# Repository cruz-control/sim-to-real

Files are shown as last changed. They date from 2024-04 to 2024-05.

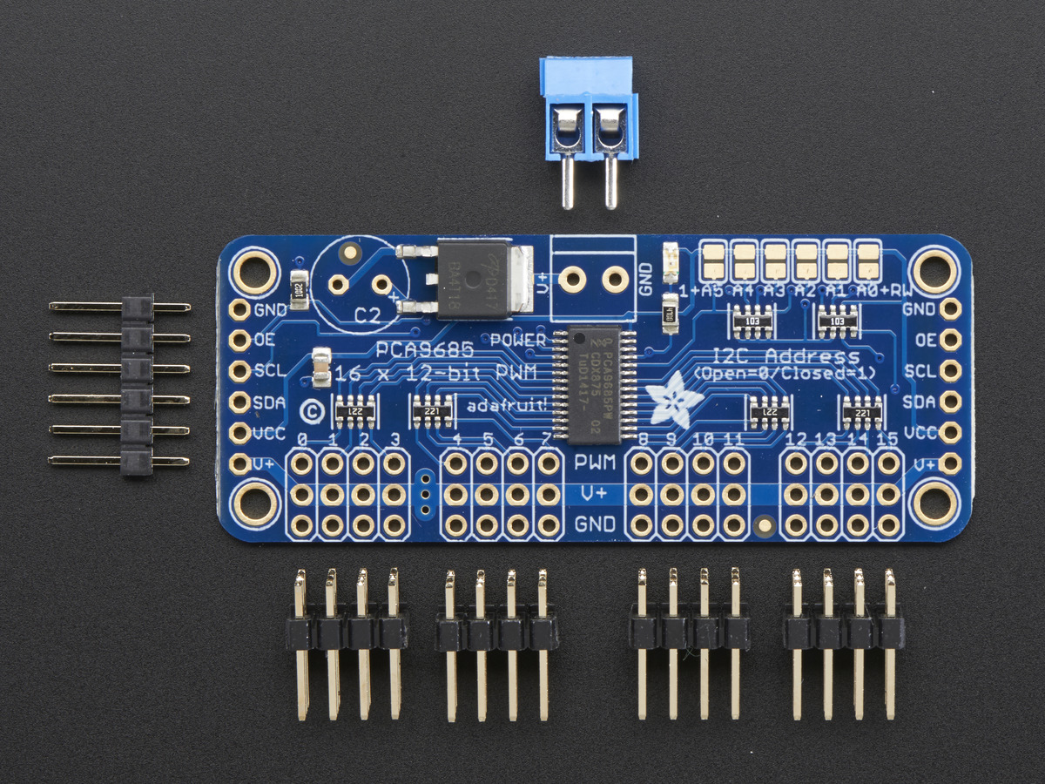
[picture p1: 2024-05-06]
PCB_v3/Adafruit-16-Channel-PWM-Servo-Driver-PCB-master/assets/image.jpg

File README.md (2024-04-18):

# Sim-to-real Team

Notes: (4/17/24) 

Solutions:
Got Jetson.GPIO to import by copying into the code directory
Got voltage out on controll pin (jetson servo PWM test)

Issues:
Get Jetson.GPIO to import from default download
Get the servo to run

Links:

Gave us test code
https://forums.developer.nvidia.com/t/strange-behaviour-with-jetson-nano-devkit-pwm-signal/113004/2

Gave us secondary test code
https://stackoverflow.com/questions/69114674/enabling-and-working-with-jetson-gpio-pins-with-python

Possible solution to Jetson.GPIO importing into python
https://forums.developer.nvidia.com/t/jetson-gpio-is-installed-but-cannot-be-imported/264719

Other possible help for identifying PWM and using PWM
https://kernel.org/doc/Documentation/pwm.txt

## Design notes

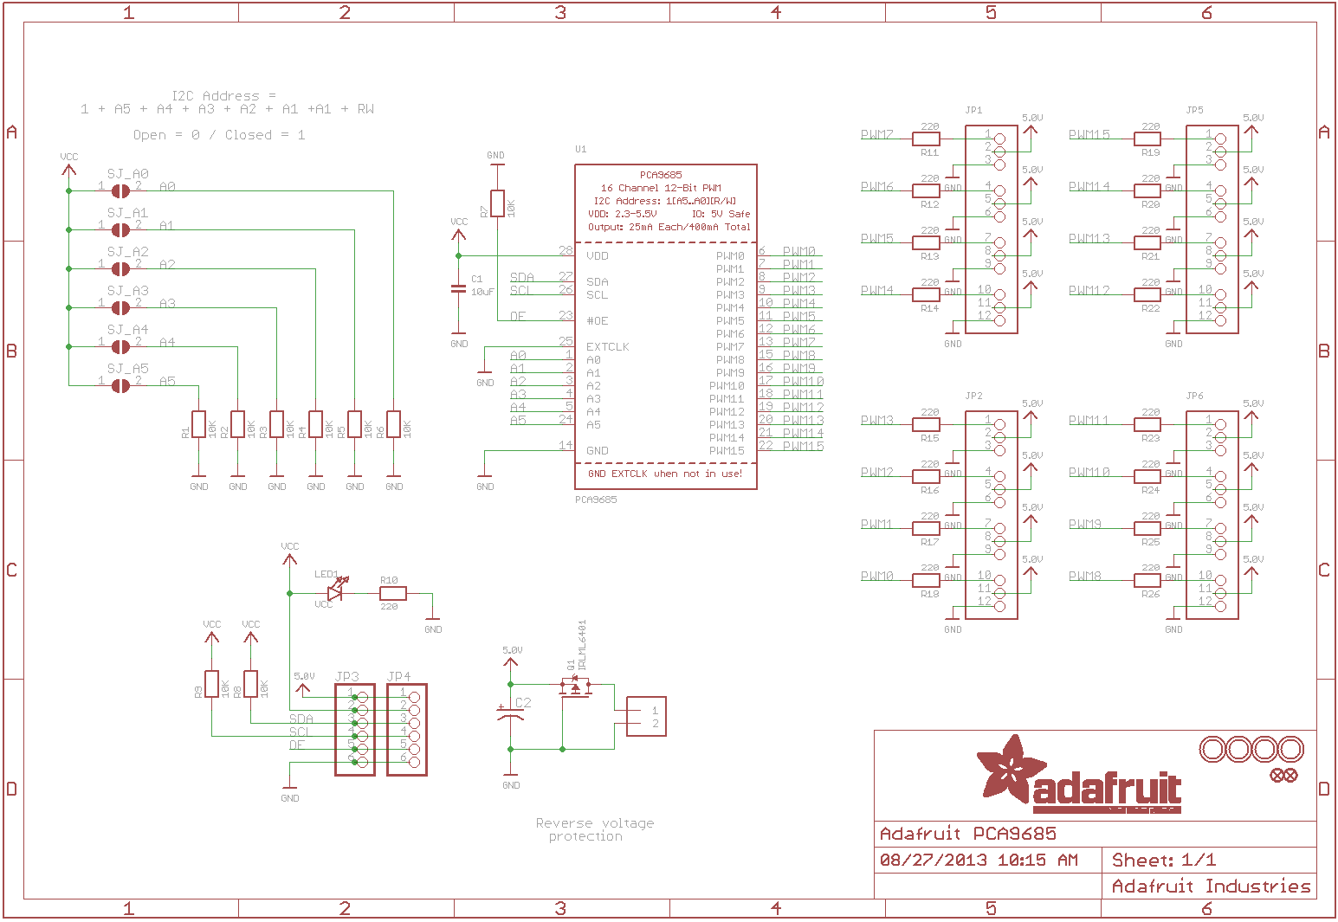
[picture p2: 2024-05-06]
PCB_v3/Adafruit-16-Channel-PWM-Servo-Driver-PCB-master/Adafruit PCA9685.png

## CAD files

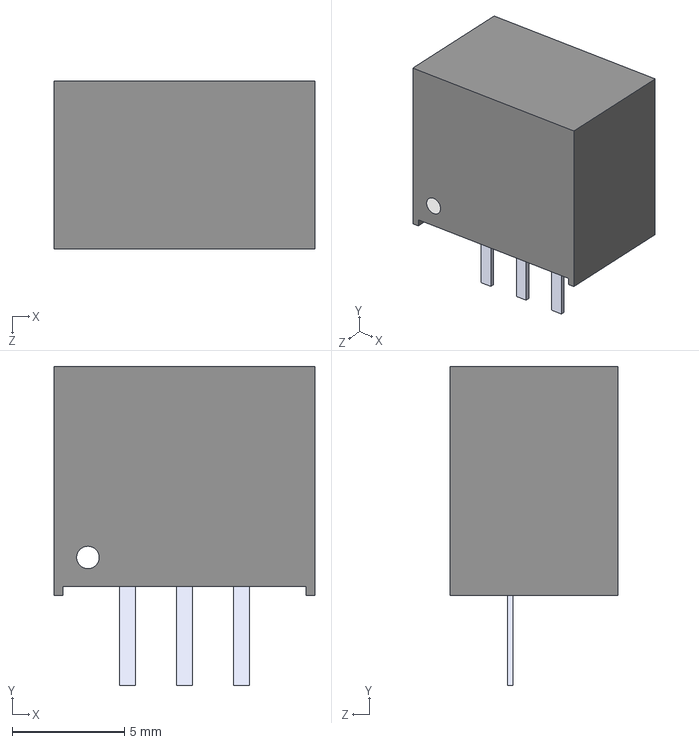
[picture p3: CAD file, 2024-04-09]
pcb-1/3d/LC78_05-3.0.STEP
11.6 x 14.2 x 7.50 mm

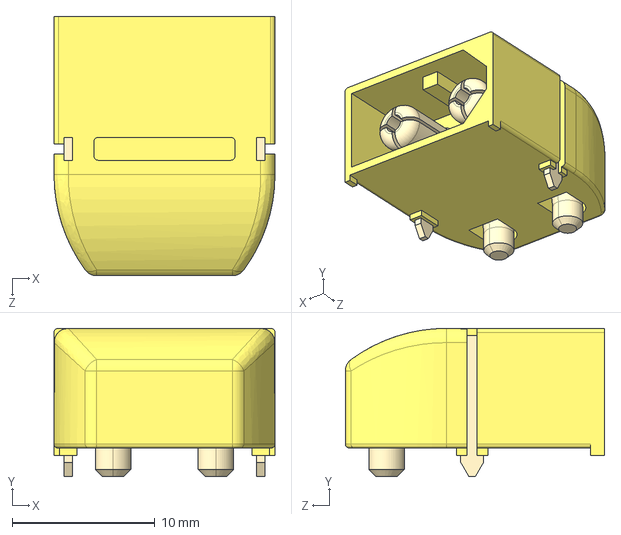
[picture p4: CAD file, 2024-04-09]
pcb-1/3d/XT60PW MALE.STEP
15.5 x 10.4 x 18.2 mm

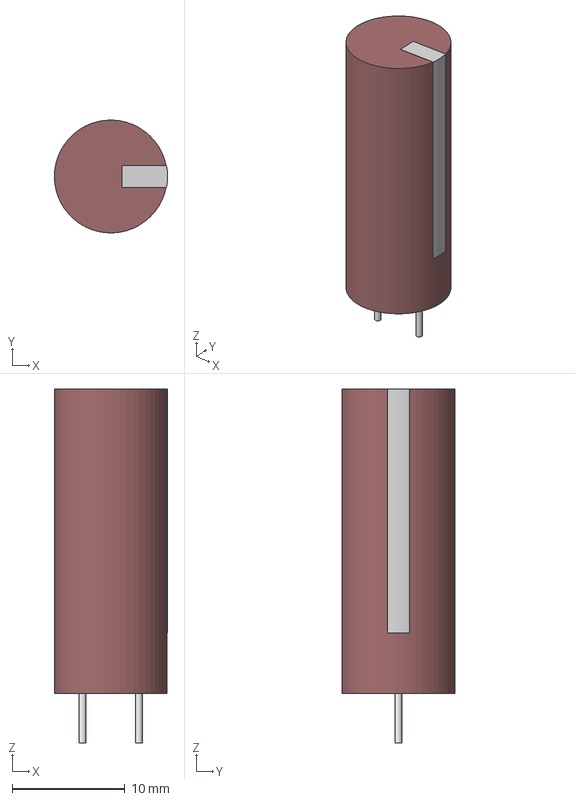
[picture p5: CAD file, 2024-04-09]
pcb-1/3d/CAP_UAQ_10X25_NCH.step
10.0 x 10.0 x 31.4 mm

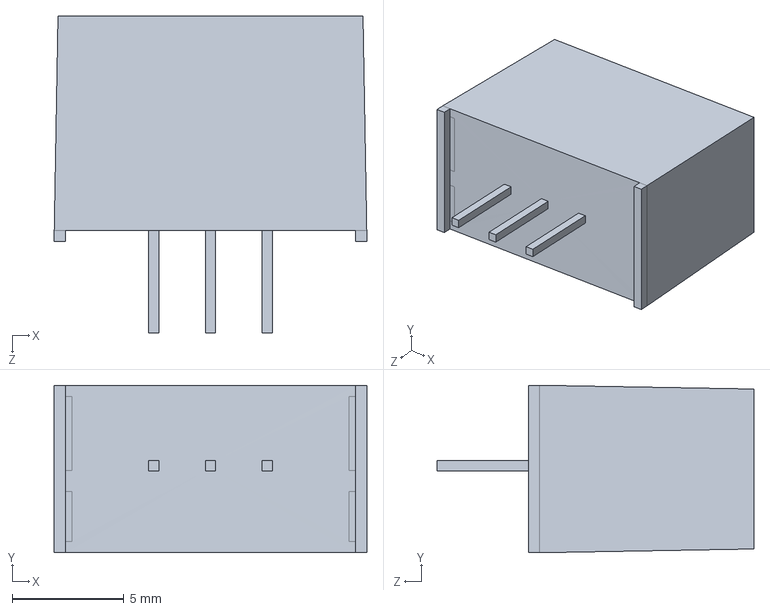
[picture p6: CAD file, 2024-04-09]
pcb-1/3d/tsr2_3d_drawing.stp
14.0 x 7.50 x 14.2 mm

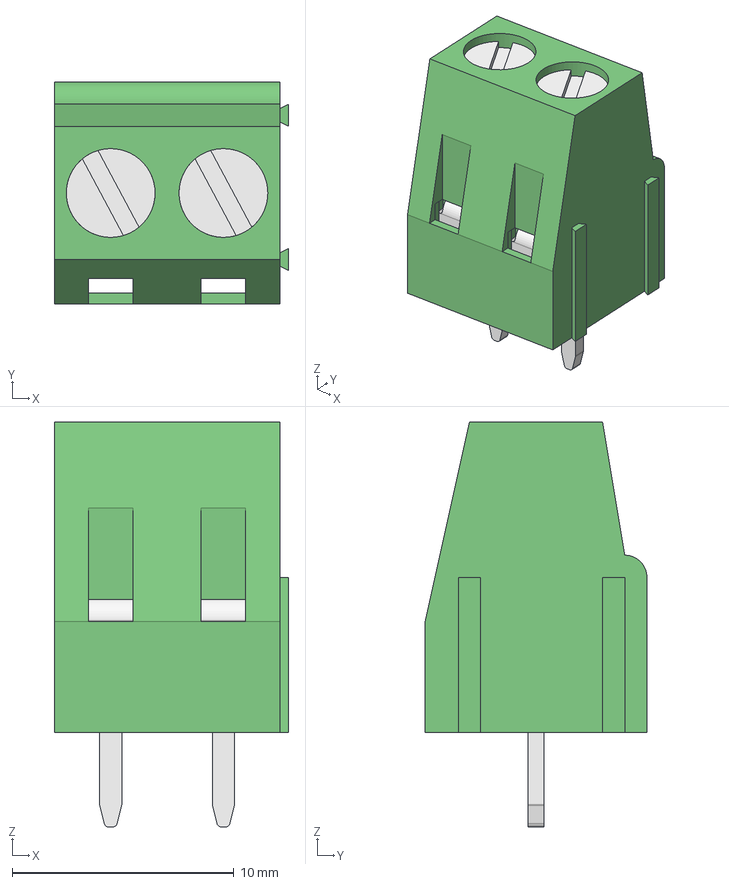
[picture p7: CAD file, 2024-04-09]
pcb-1/3d/Terminal Block 2P.step
10.6 x 10.0 x 18.2 mm
Pin (1) (19)
Tornillo (1) (19)
Cubo interno (1) (19)
Pin (1) (1) (18)
Tornillo (1) (1) (18)
Cubo interno (1) (1) (18)
Pin (1) (11)
Tornillo (1) (11)
Cubo interno (1) (11)
Pin (1) (1) (10)
Tornillo (1) (1) (10)
Cubo interno (1) (1) (10)

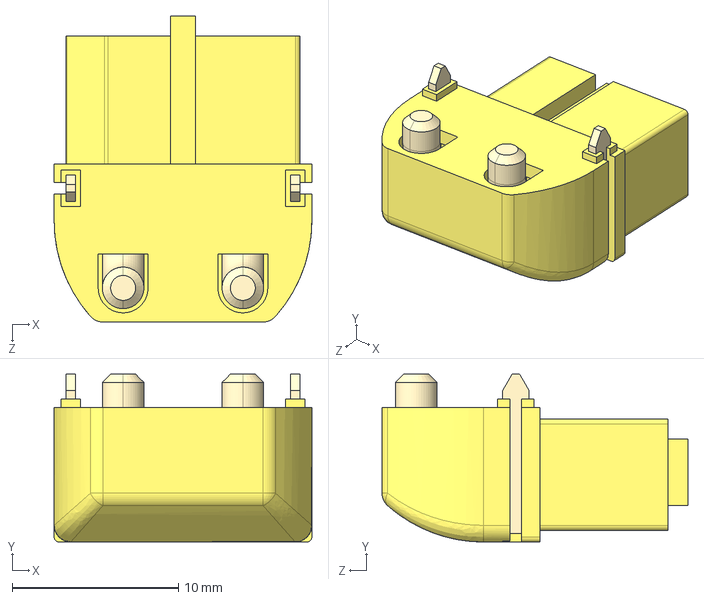
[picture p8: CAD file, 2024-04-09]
pcb-1/3d/XT60PW FEMALE.STEP
15.5 x 10.1 x 18.4 mm

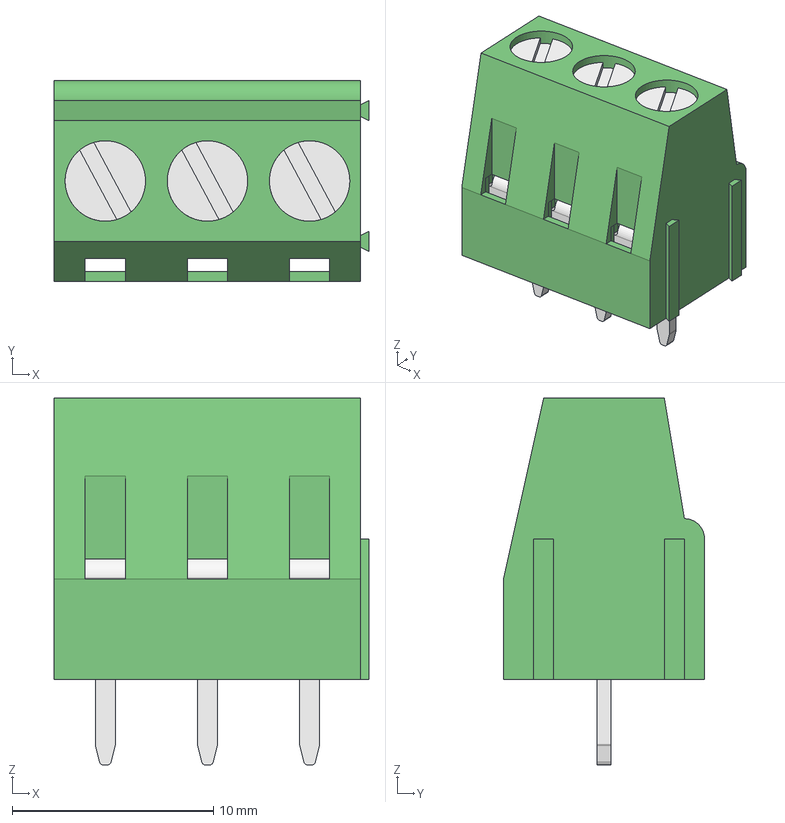
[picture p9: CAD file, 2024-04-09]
pcb-1/3d/Terminal Block 3P.step
15.6 x 10.0 x 18.2 mm
Pin (1) (19) (1)
Tornillo (1) (19) (1)
Cubo interno (1) (19) (1)
Pin (1) (1) (18) (1)
Tornillo (1) (1) (18) (1)
Cubo interno (1) (1) (18) (1)
Pin (1) (11) (1)
Tornillo (1) (11) (1)
Cubo interno (1) (11) (1)
Pin (1) (1) (10) (1)
Tornillo (1) (1) (10) (1)
Cubo interno (1) (1) (10) (1)
Pin (1) (17)
Tornillo (1) (17)
Cubo interno (1) (17)
Pin (1) (1) (16)
Tornillo (1) (1) (16)
Cubo interno (1) (1) (16)

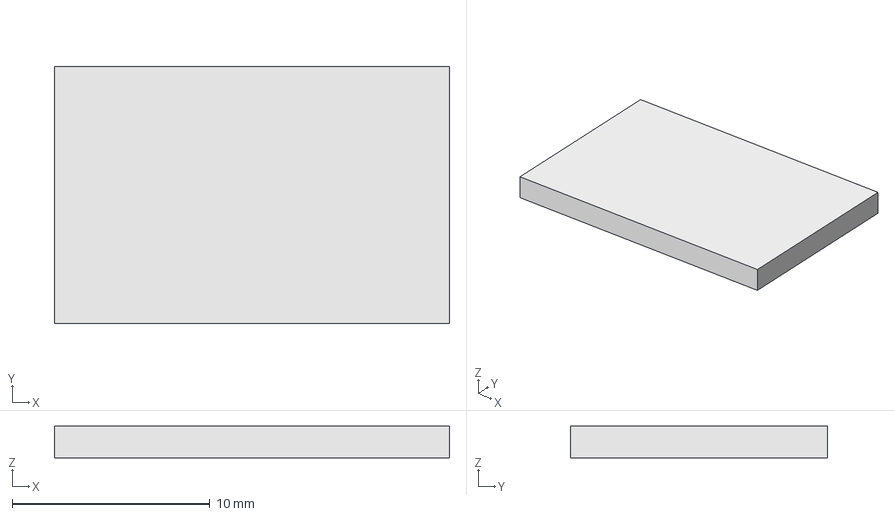
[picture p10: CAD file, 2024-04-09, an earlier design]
pcb-v2/3d/Unnamed2-Cube.step
20.0 x 13.0 x 1.60 mm

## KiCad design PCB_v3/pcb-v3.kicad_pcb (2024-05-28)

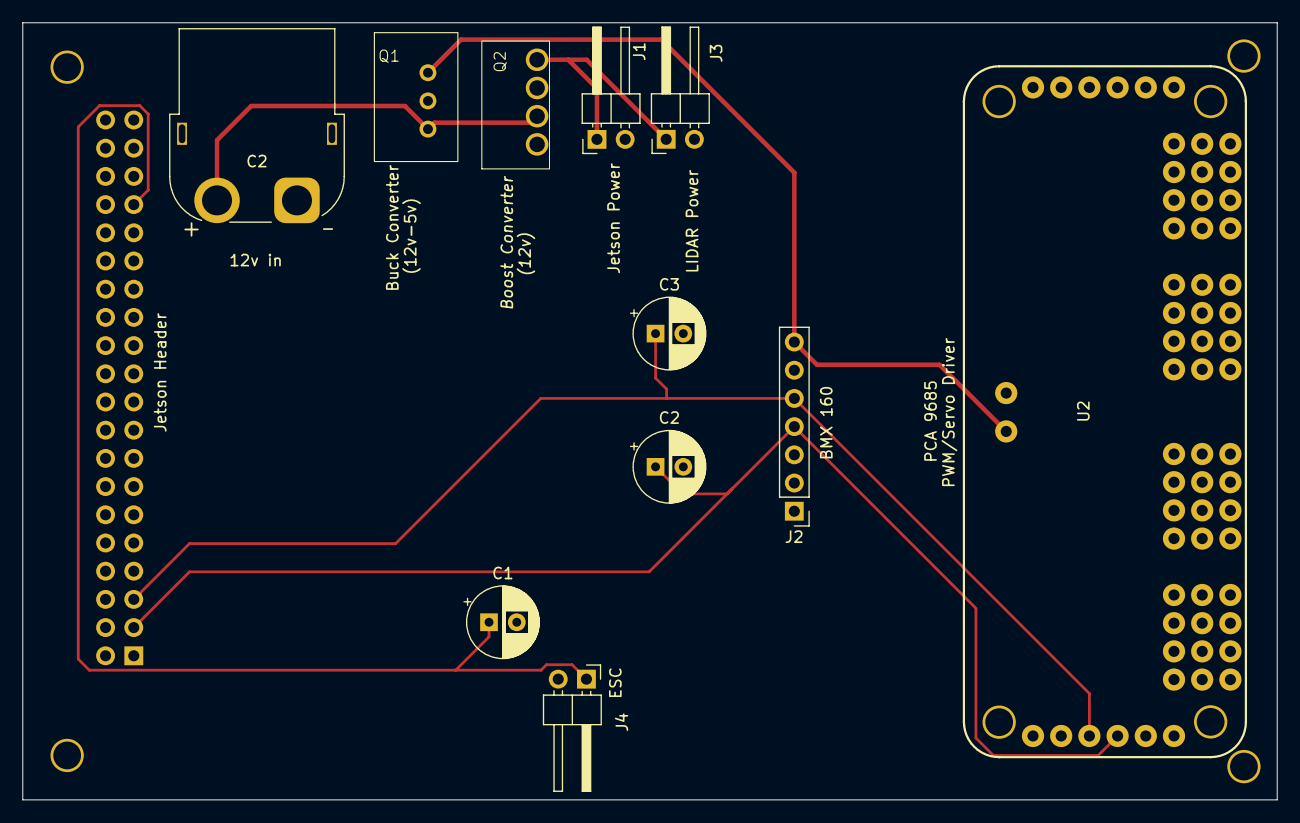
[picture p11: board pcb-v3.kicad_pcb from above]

Board: 2 copper layers, 113.0 x 70.0 mm, 12 parts (1 on the bottom side), 7 nets.

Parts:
C1, C2, C3: CP_Radial_D6.3mm_P2.50mm
C2#2: AMASS_XT60PW-F_1x02_P7.20mm_Horizontal
J1, J3, J4: Screw_Terminal_01x02; PinHeader_1x02_P2.54mm_Horizontal
J2: Conn_01x07_Socket; PinHeader_1x07_P2.54mm_Vertical
J5: Conn_02x20_Odd_Even; PinSocket_2x20_P2.54mm_Vertical
Q1: LC78_05-3.0
Q2: CRE1S Boost Converter
U2: Adafruit PCA9685 rev C (1)

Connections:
+5V: J2.7, Q1.3 (Vout), U2.24 (A5)
+12V: C2#2.2 (Vout), Q1.1 (Vin), Q2.2 (+Vin)
ESC: C1.1, J4.1, J5.33
GND: C1.2, C2.2, C2#2.1 (Vin), C3.2, J1.2, J2.3, J2.6, J3.2, J4.2, J5.6, J5.9, J5.14, J5.20, J5.25, J5.30, J5.34, J5.39, Q1.2 (GND), Q2.1 (-Vin), Q2.3 (-Vout), U2.14 (GND), U2.25 (EXTCLK)
SCL: C3.1, J2.5, J5.5, U2.4 (A3)
SDA: C2.1, J2.4, J5.3, U2.3 (A2)
STABLE_12V: J1.1, J3.1, Q2.4 (+Vout)

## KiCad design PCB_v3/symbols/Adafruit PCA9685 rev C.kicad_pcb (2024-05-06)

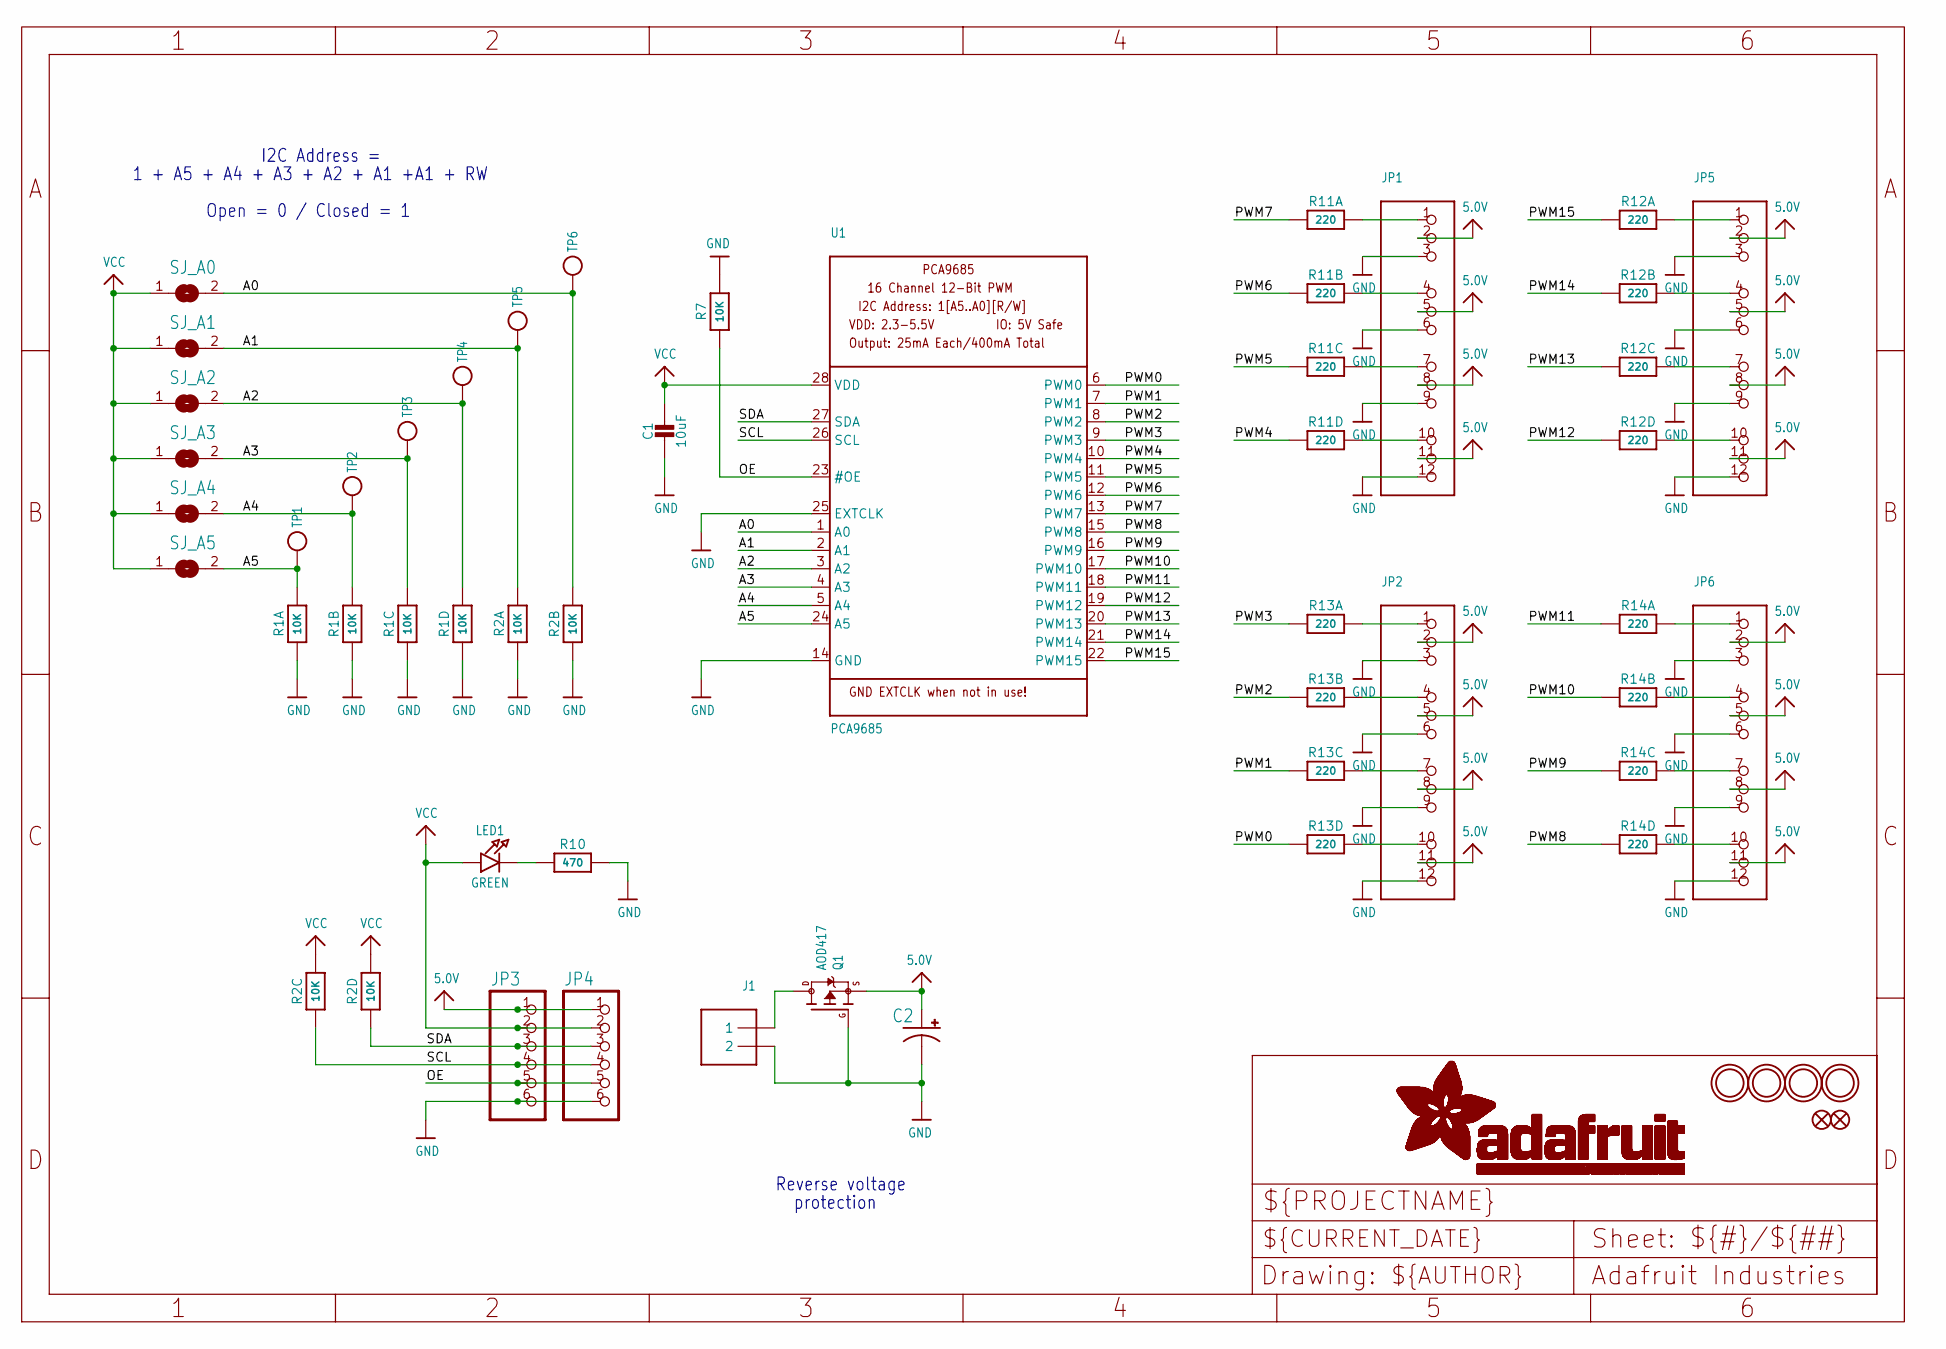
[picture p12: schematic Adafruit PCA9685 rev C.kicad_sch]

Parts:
C1: 10uF; 0805-NO
C2: CPOL-USE3.5-8; E3,5-8
FID1, FID2: FIDUCIAL""; FIDUCIAL_1MM
J1: TERMBLOCK_1X2; TERMBLOCK_1X2-3.5MM
JP1, JP2, JP5, JP6: HEADER-3X04; 3X04
JP3, JP4: PINHD-1X6CB; 1X06-CLEANBIG
LED1: GREEN; CHIPLED_0805_NOOUTLINE
Q1: AOD417; TO252
R1, R2: 10K; RESPACK_4X0603
R7: 10K; 0805-NO
R10: 470; _0805MP
R11, R12, R13, R14: 220; RESPACK_4X0603
SJ_A0, SJ_A1, SJ_A2, SJ_A3, SJ_A4, SJ_A5: SOLDERJUMPERREFLOW_NOPASTE; SOLDERJUMPER_REFLOW_NOPASTE
TP1, TP2, TP3, TP4, TP5, TP6: TESTPOINTROUND1MM; TESTPOINT_ROUND_1MM
U1: PCA9685; TSSOP28
U$47, U$48, U$49, U$50: MOUNTINGHOLE2.5; MOUNTINGHOLE_2.5_PLATED

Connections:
5.0V: C2.+, JP1.2, JP1.5, JP1.8, JP1.11, JP2.2, JP2.5, JP2.8, JP2.11, JP3.1, JP4.1, JP5.2, JP5.5, JP5.8, JP5.11, JP6.2, JP6.5, JP6.8, JP6.11, Q1.2 (S)
/A0: R2.7 (2), SJ_A0.2, TP6.P$1, U1.1 (A0)
/A1: R2.8 (2), SJ_A1.2, TP5.P$1, U1.2 (A1)
/A2: R1.5 (2), SJ_A2.2, TP4.P$1, U1.3 (A2)
/A3: R1.6 (2), SJ_A3.2, TP3.P$1, U1.4 (A3)
/A4: R1.7 (2), SJ_A4.2, TP2.P$1, U1.5 (A4)
/A5: R1.8 (2), SJ_A5.2, TP1.P$1, U1.24 (A5)
/OE: JP3.5, JP4.5, R7.1, U1.23 (#OE)
/PWM0: R13.4 (1), U1.6 (PWM0)
/PWM1: R13.3 (1), U1.7 (PWM1)
/PWM2: R13.2 (1), U1.8 (PWM2)
/PWM3: R13.1, U1.9 (PWM3)
/PWM4: R11.4 (1), U1.10 (PWM4)
/PWM5: R11.3 (1), U1.11 (PWM5)
/PWM6: R11.2 (1), U1.12 (PWM6)
/PWM7: R11.1, U1.13 (PWM7)
/PWM8: R14.4 (1), U1.15 (PWM8)
/PWM9: R14.3 (1), U1.16 (PWM9)
/PWM10: R14.2 (1), U1.17 (PWM10)
/PWM11: R14.1, U1.18 (PWM11)
/PWM12: R12.4 (1), U1.19 (PWM12)
/PWM13: R12.3 (1), U1.20 (PWM13)
/PWM14: R12.2 (1), U1.21 (PWM14)
/PWM15: R12.1, U1.22 (PWM15)
/SCL: JP3.4, JP4.4, R2.3 (1), U1.26 (SCL)
/SDA: JP3.3, JP4.3, R2.4 (1), U1.27 (SDA)
GND: C1.2, C2.-, J1.2, JP1.3, JP1.6, JP1.9, JP1.12, JP2.3, JP2.6, JP2.9, JP2.12, JP3.6, JP4.6, JP5.3, JP5.6, JP5.9, JP5.12, JP6.3, JP6.6, JP6.9, JP6.12, Q1.1 (G), R1.1, R1.2 (1), R1.3 (1), R1.4 (1), R2.1, R2.2 (1), R7.2, R10.2, U1.14 (GND), U1.25 (EXTCLK)
unnamed: LED1.C, R10.1
unnamed: J1.1, Q1.3 (D)
unnamed: JP1.1, R11.8 (2)
unnamed: JP1.4, R11.7 (2)
unnamed: JP1.7, R11.6 (2)
unnamed: JP1.10, R11.5 (2)
unnamed: JP5.1, R12.8 (2)
unnamed: JP5.4, R12.7 (2)
unnamed: JP5.7, R12.6 (2)
unnamed: JP5.10, R12.5 (2)
unnamed: JP2.1, R13.8 (2)
unnamed: JP2.4, R13.7 (2)
unnamed: JP2.7, R13.6 (2)
unnamed: JP2.10, R13.5 (2)
unnamed: JP6.1, R14.8 (2)
unnamed: JP6.4, R14.7 (2)
unnamed: JP6.7, R14.6 (2)
unnamed: JP6.10, R14.5 (2)
VCC: C1.1, JP3.2, JP4.2, LED1.A, R2.5 (2), R2.6 (2), SJ_A0.1, SJ_A1.1, SJ_A2.1, SJ_A3.1, SJ_A4.1, SJ_A5.1, U1.28 (VDD)

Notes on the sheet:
protection
Reverse voltage
I2C Address =
Open = 0 / Closed = 1
1 + A5 + A4 + A3 + A2 + A1 +A1 + RW

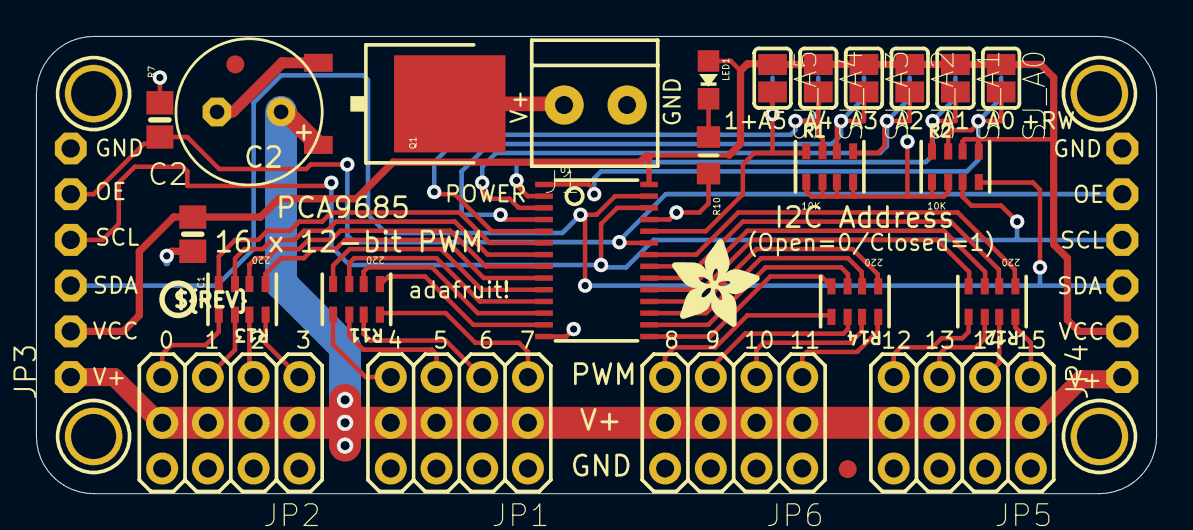
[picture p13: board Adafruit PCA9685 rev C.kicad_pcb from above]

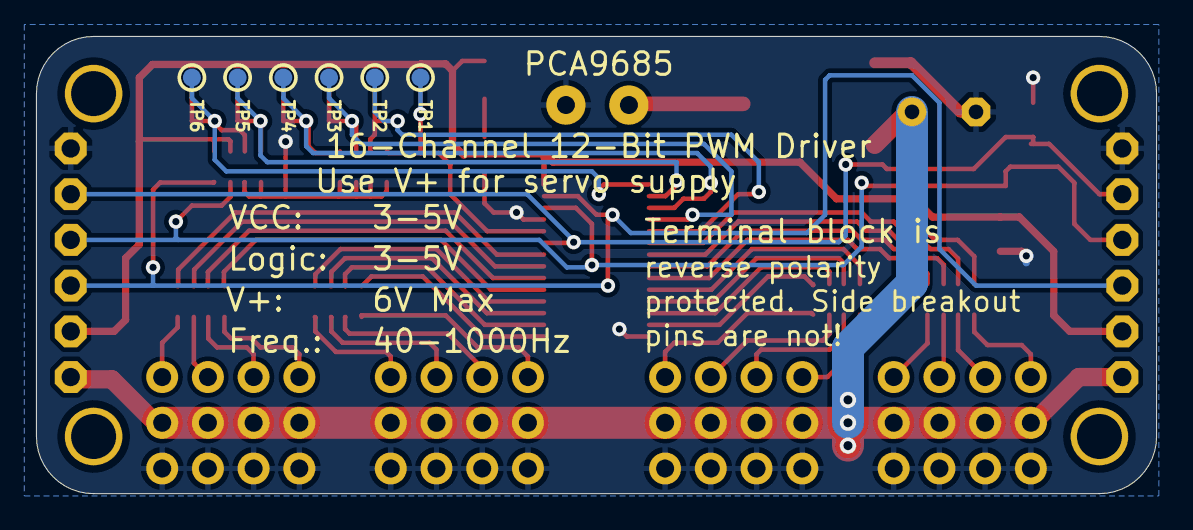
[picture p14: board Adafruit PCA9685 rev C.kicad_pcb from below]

Board: 2 copper layers, 62.2 x 25.4 mm, 40 parts (6 on the bottom side), 46 nets.

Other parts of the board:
U$51: ADAFRUIT_5MM
U$54: PCBFEAT-REV-040

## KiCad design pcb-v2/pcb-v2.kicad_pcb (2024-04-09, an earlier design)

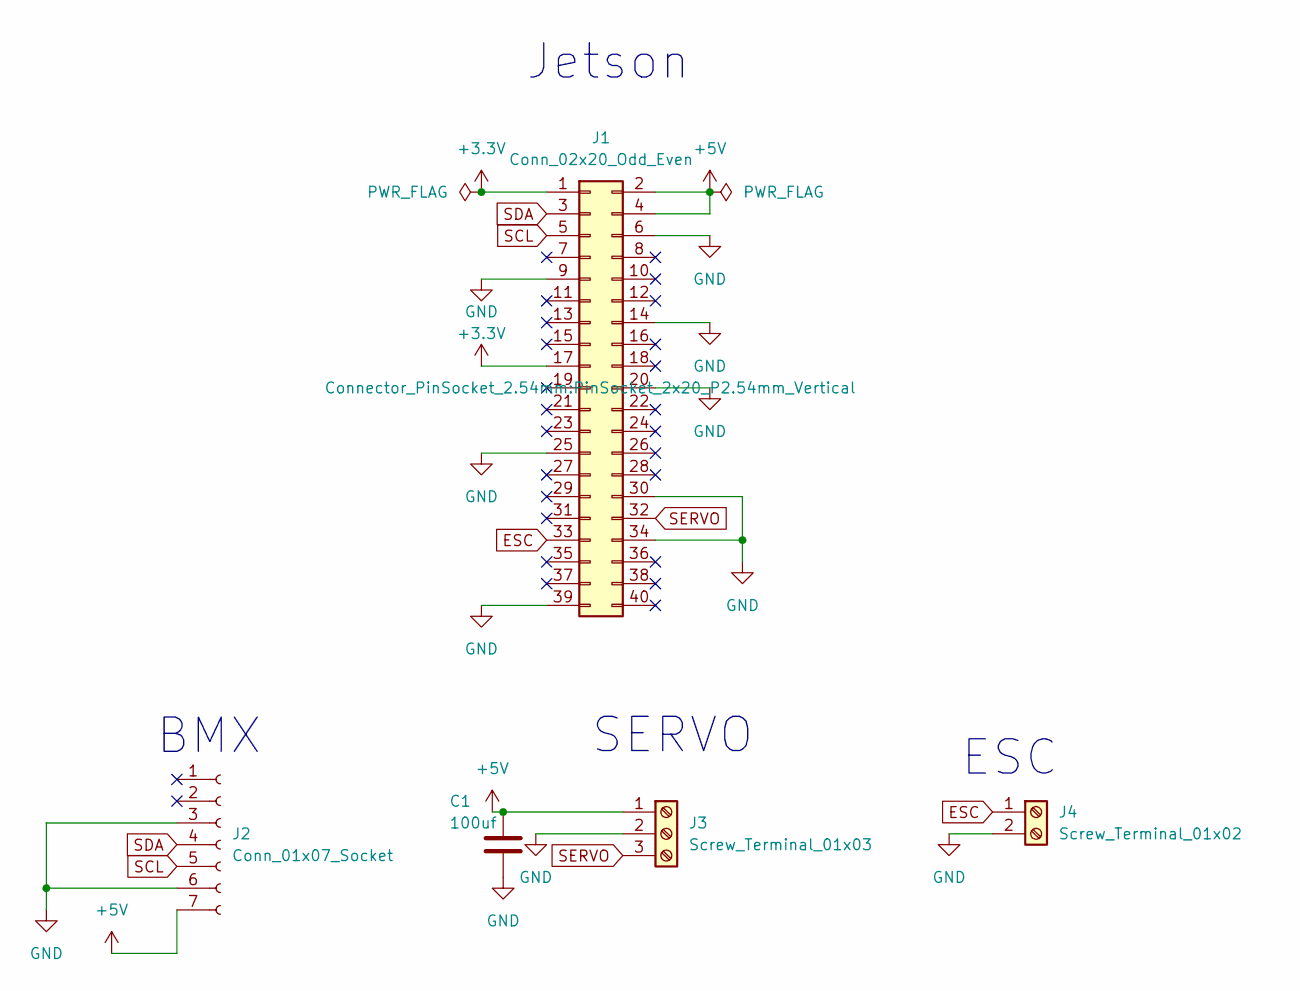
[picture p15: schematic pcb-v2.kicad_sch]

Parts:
C1: 100uf; CP_Radial_Tantal_D10.5mm_P5.00mm
J1: Conn_02x20_Odd_Even; PinSocket_2x20_P2.54mm_Vertical
J2: Conn_01x07_Socket; PinHeader_1x07_P2.54mm_Vertical
J3: Screw_Terminal_01x03; PinHeader_1x03_P2.54mm_Horizontal
J4: Screw_Terminal_01x02; PinHeader_1x02_P2.54mm_Horizontal

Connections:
+3.3V: J1.1, J1.17
+5V: C1.1, J1.2, J1.4, J2.7, J3.1
ESC: J1.33, J4.1
GND: C1.2, J1.6, J1.9, J1.14, J1.20, J1.25, J1.30, J1.34, J1.39, J2.3, J2.6, J3.2, J4.2
SCL: J1.5, J2.5
SDA: J1.3, J2.4
SERVO: J1.32, J3.3

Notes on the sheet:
BMX
SERVO
ESC
Jetson

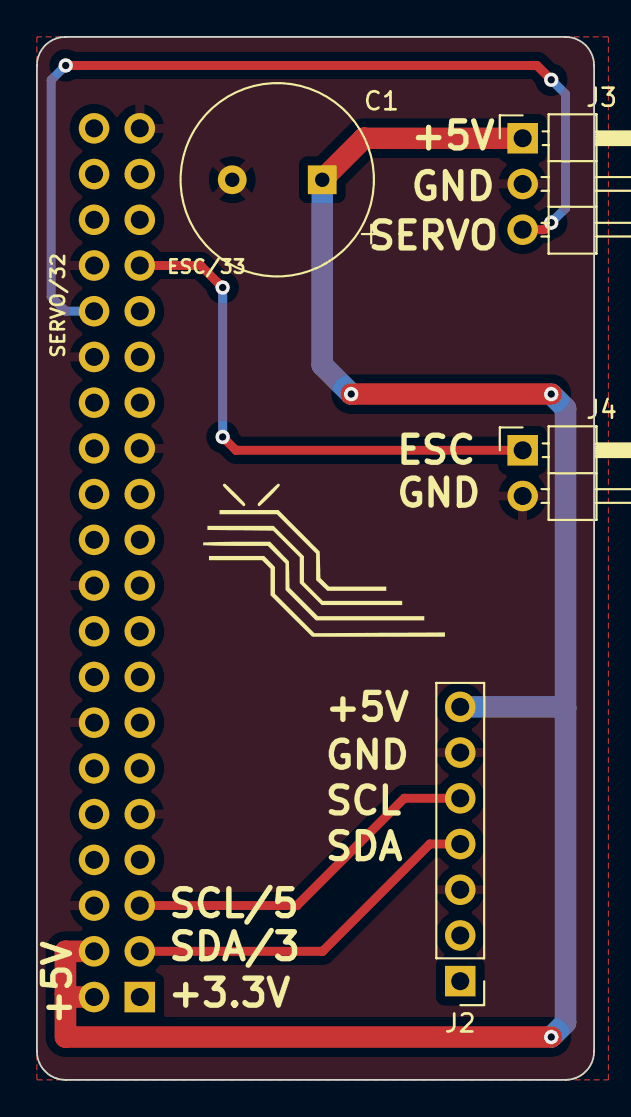
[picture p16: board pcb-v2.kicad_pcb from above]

Board: 2 copper layers, 31.0 x 57.9 mm, 5 parts (1 on the bottom side), 7 nets.

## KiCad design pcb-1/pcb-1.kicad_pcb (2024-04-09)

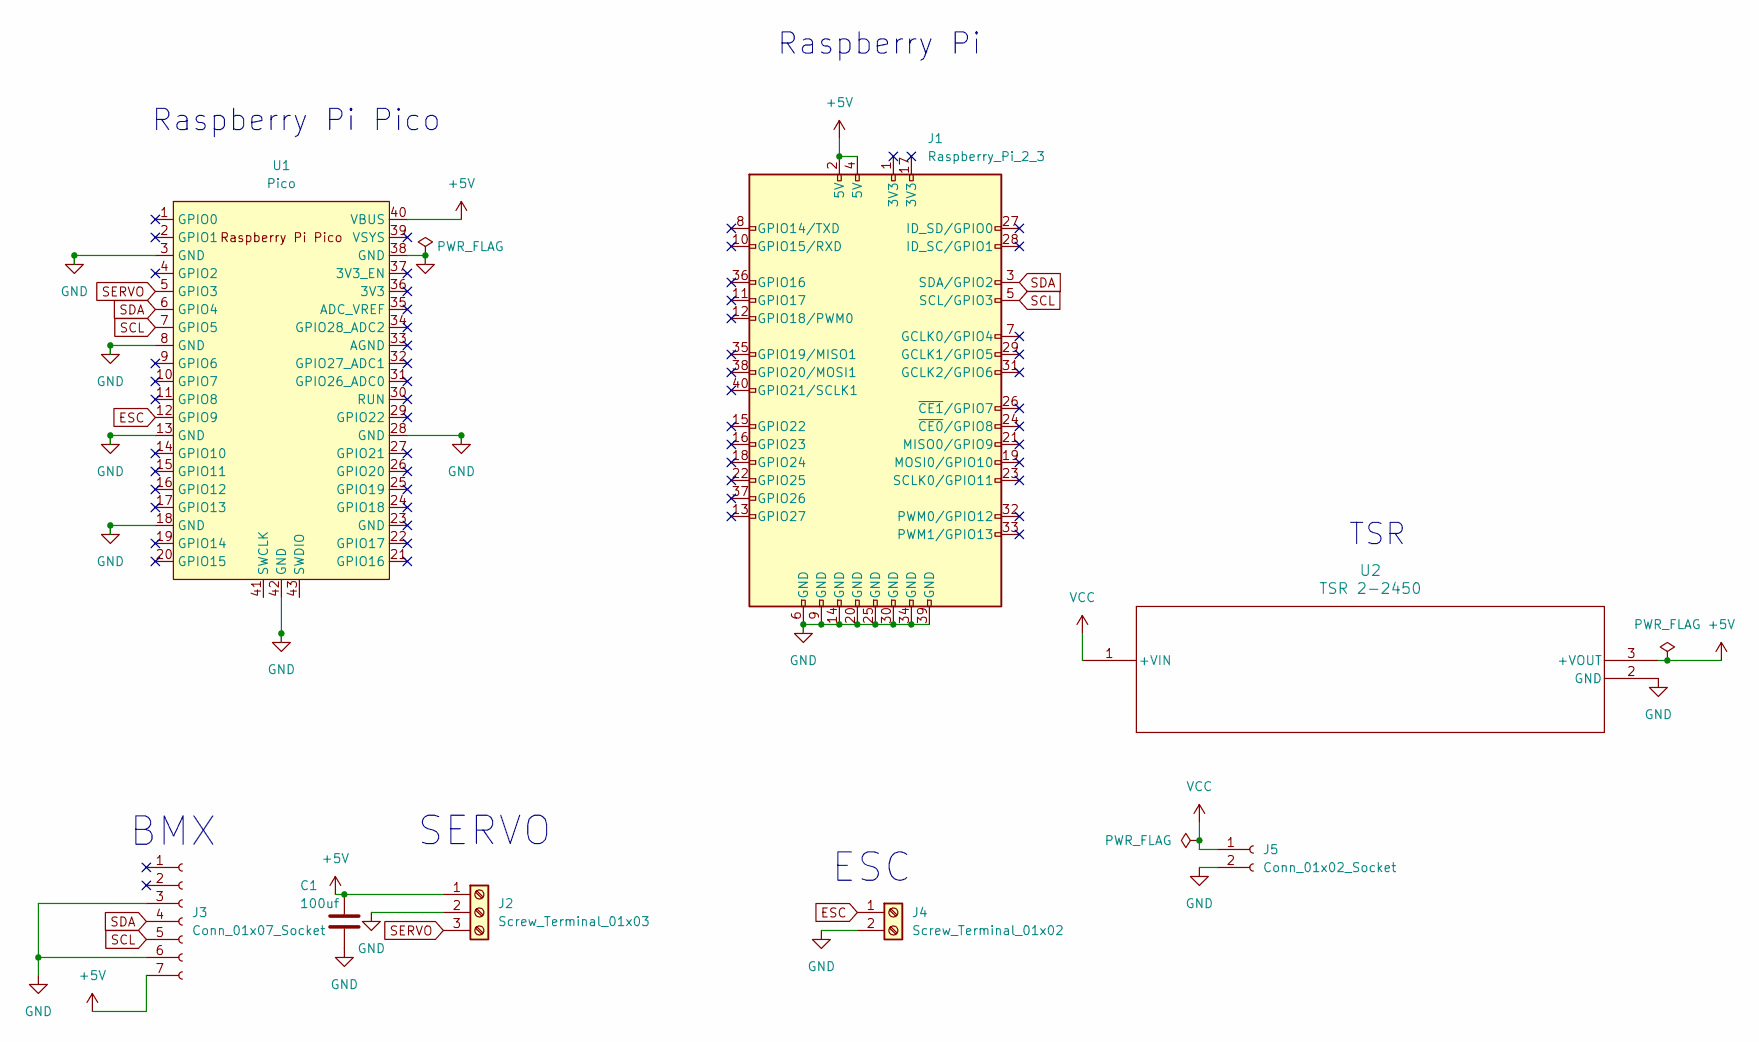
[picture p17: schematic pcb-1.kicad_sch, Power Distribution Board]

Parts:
C1: 100uf; CP_Radial_Tantal_D10.5mm_P5.00mm
J1: Raspberry_Pi_2_3; raspberrypi_2_3
J2: Screw_Terminal_01x03; CONN_1935174_PXC
J3: Conn_01x07_Socket; PinHeader_1x07_P2.54mm_Vertical
J4: Screw_Terminal_01x02; CONN2_710002_WRE
J5: Conn_01x02_Socket; AMASS_XT60-F_1x02_P7.20mm_Vertical
U1: Pico; RPi_Pico_SMD_TH
U2: TSR 2-2450; TSR 2-2450_TRP

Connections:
+5V: C1.1, J1.2 (5V), J1.4 (5V), J2.1, J3.7, U1.40 (VBUS), U2.3 (+VOUT)
ESC: J4.1, U1.12 (GPIO9)
GND: C1.2, J1.6 (GND), J1.9 (GND), J1.14 (GND), J1.20 (GND), J1.25 (GND), J1.30 (GND), J1.34 (GND), J1.39 (GND), J2.2, J3.3, J3.6, J4.2, J5.2, U1.3 (GND), U1.8 (GND), U1.13 (GND), U1.18 (GND), U1.28 (GND), U1.38 (GND), U1.42 (GND), U2.2 (GND)
SCL: J1.5 (SCL/GPIO3), J3.5, U1.7 (GPIO5)
SDA: J1.3 (SDA/GPIO2), J3.4, U1.6 (GPIO4)
SERVO: J2.3, U1.5 (GPIO3)
VCC: J5.1, U2.1 (+VIN)

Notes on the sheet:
Raspberry Pi
TSR
BMX
ESC
Raspberry Pi Pico
SERVO

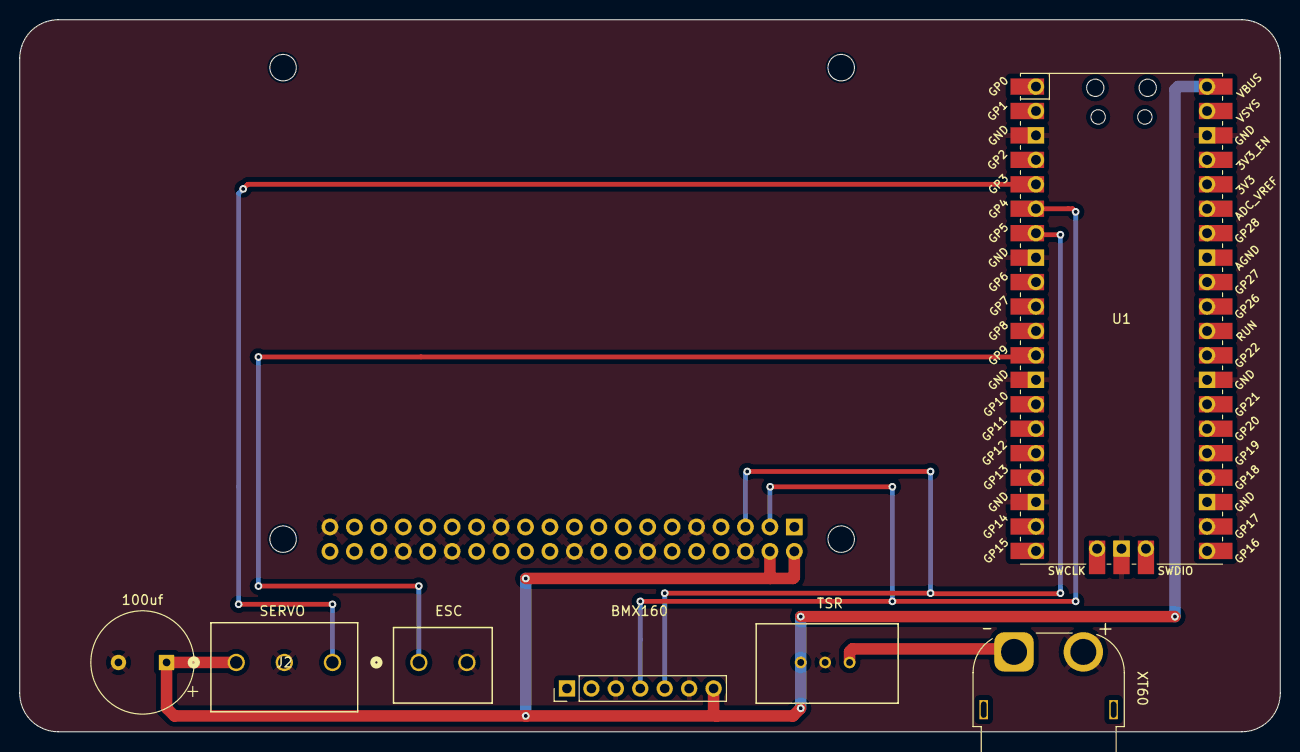
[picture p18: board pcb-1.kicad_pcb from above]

Board: 2 copper layers, 131.0 x 74.0 mm, 9 parts (0 on the bottom side), 7 nets.

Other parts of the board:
BMX160-Drawing: LOGO

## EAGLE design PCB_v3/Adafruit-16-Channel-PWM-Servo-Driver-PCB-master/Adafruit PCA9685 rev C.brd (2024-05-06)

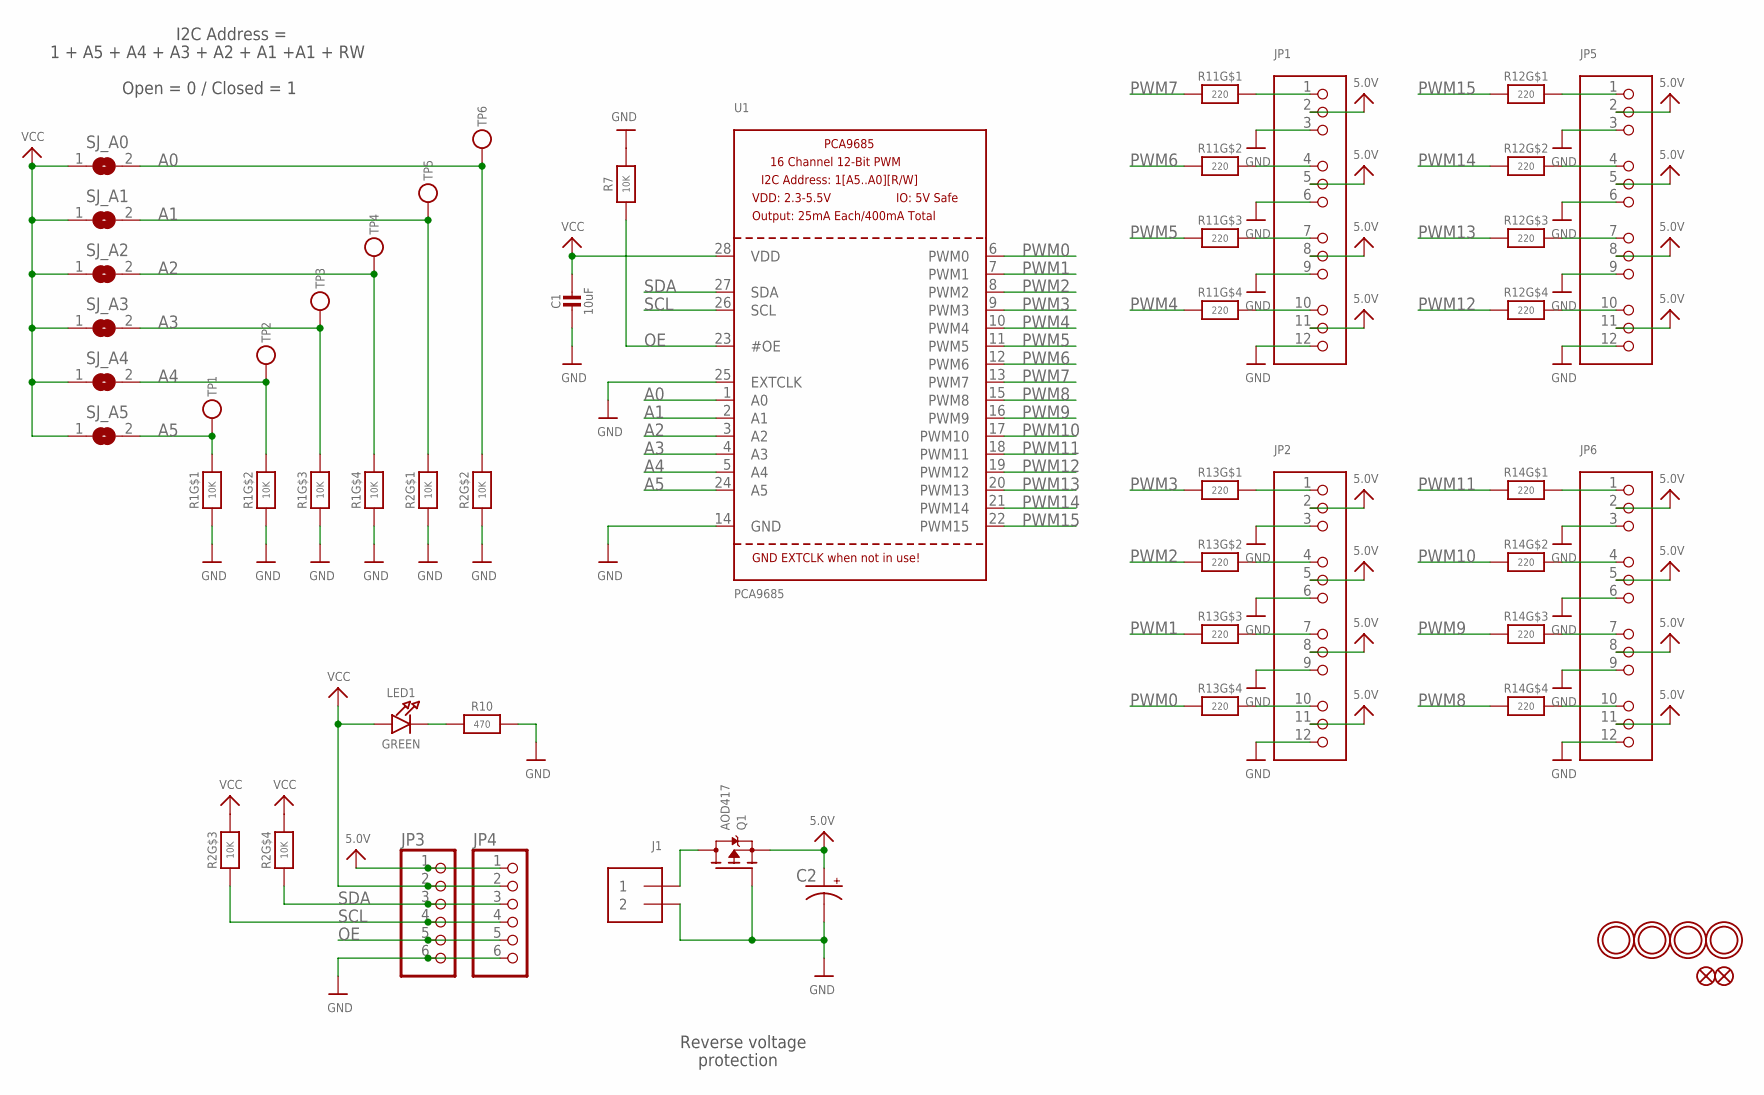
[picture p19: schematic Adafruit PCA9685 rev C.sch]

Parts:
C1: 10uF; 0805-NO
C2: CPOL-USE3.5-8; E3,5-8
FID1, FID2: FIDUCIAL""; FIDUCIAL_1MM
J1: TERMBLOCK_1X2; TERMBLOCK_1X2-3.5MM
JP1, JP2, JP5, JP6: HEADER-3X04; 3X04
JP3, JP4: PINHD-1X6CB; 1X06-CLEANBIG
LED1: GREEN; CHIPLED_0805_NOOUTLINE
Q1: AOD417; TO252
R1, R2: 10K; RESPACK_4X0603
R7: 10K; 0805-NO
R10: 470; _0805MP
R11, R12, R13, R14: 220; RESPACK_4X0603
SJ_A0, SJ_A1, SJ_A2, SJ_A3, SJ_A4, SJ_A5: SOLDERJUMPERREFLOW_NOPASTE; SOLDERJUMPER_REFLOW_NOPASTE
TP1, TP2, TP3, TP4, TP5, TP6: TESTPOINTROUND1MM; TESTPOINT_ROUND_1MM
U1: PCA9685; TSSOP28
U$47, U$48, U$49, U$50: MOUNTINGHOLE2.5; MOUNTINGHOLE_2.5_PLATED

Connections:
5.0V: C2.+, JP1.2, JP1.5, JP1.8, JP1.11, JP2.2, JP2.5, JP2.8, JP2.11, JP3.1, JP4.1, JP5.2, JP5.5, JP5.8, JP5.11, JP6.2, JP6.5, JP6.8, JP6.11, Q1.2 (S)
A0: R2.7 (2), SJ_A0.2, TP6.P$1, U1.1 (A0)
A1: R2.8 (2), SJ_A1.2, TP5.P$1, U1.2 (A1)
A2: R1.5 (2), SJ_A2.2, TP4.P$1, U1.3 (A2)
A3: R1.6 (2), SJ_A3.2, TP3.P$1, U1.4 (A3)
A4: R1.7 (2), SJ_A4.2, TP2.P$1, U1.5 (A4)
A5: R1.8 (2), SJ_A5.2, TP1.P$1, U1.24 (A5)
GND: C1.2, C2.-, J1.2, JP1.3, JP1.6, JP1.9, JP1.12, JP2.3, JP2.6, JP2.9, JP2.12, JP3.6, JP4.6, JP5.3, JP5.6, JP5.9, JP5.12, JP6.3, JP6.6, JP6.9, JP6.12, Q1.1 (G), R1.1, R1.2 (1), R1.3 (1), R1.4 (1), R2.1, R2.2 (1), R7.2, R10.2, U1.14 (GND), U1.25 (EXTCLK)
unnamed: LED1.C, R10.1
unnamed: JP1.4, R11.7 (2)
unnamed: JP1.1, R11.8 (2)
unnamed: JP1.7, R11.6 (2)
unnamed: JP1.10, R11.5 (2)
unnamed: JP2.1, R13.8 (2)
unnamed: JP2.4, R13.7 (2)
unnamed: JP2.7, R13.6 (2)
unnamed: JP2.10, R13.5 (2)
unnamed: JP6.10, R14.5 (2)
unnamed: JP6.7, R14.6 (2)
unnamed: JP6.4, R14.7 (2)
unnamed: JP6.1, R14.8 (2)
unnamed: JP5.10, R12.5 (2)
unnamed: JP5.7, R12.6 (2)
unnamed: JP5.4, R12.7 (2)
unnamed: JP5.1, R12.8 (2)
OE: JP3.5, JP4.5, R7.1, U1.23 (#OE)
PWM0: R13.4 (1), U1.6 (PWM0)
PWM1: R13.3 (1), U1.7 (PWM1)
PWM2: R13.2 (1), U1.8 (PWM2)
PWM3: R13.1, U1.9 (PWM3)
PWM4: R11.4 (1), U1.10 (PWM4)
PWM5: R11.3 (1), U1.11 (PWM5)
PWM6: R11.2 (1), U1.12 (PWM6)
PWM7: R11.1, U1.13 (PWM7)
PWM8: R14.4 (1), U1.15 (PWM8)
PWM9: R14.3 (1), U1.16 (PWM9)
PWM10: R14.2 (1), U1.17 (PWM10)
PWM11: R14.1, U1.18 (PWM11)
PWM12: R12.4 (1), U1.19 (PWM12)
PWM13: R12.3 (1), U1.20 (PWM13)
PWM14: R12.2 (1), U1.21 (PWM14)
PWM15: R12.1, U1.22 (PWM15)
PWRIN: J1.1, Q1.3 (D)
SCL: JP3.4, JP4.4, R2.3 (1), U1.26 (SCL)
SDA: JP3.3, JP4.3, R2.4 (1), U1.27 (SDA)
VCC: C1.1, JP3.2, JP4.2, LED1.A, R2.5 (2), R2.6 (2), SJ_A0.1, SJ_A1.1, SJ_A2.1, SJ_A3.1, SJ_A4.1, SJ_A5.1, U1.28 (VDD)

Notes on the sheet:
Reverse voltage
protection
1 + A5 + A4 + A3 + A2 + A1 +A1 + RW
I2C Address =
Open = 0 / Closed = 1

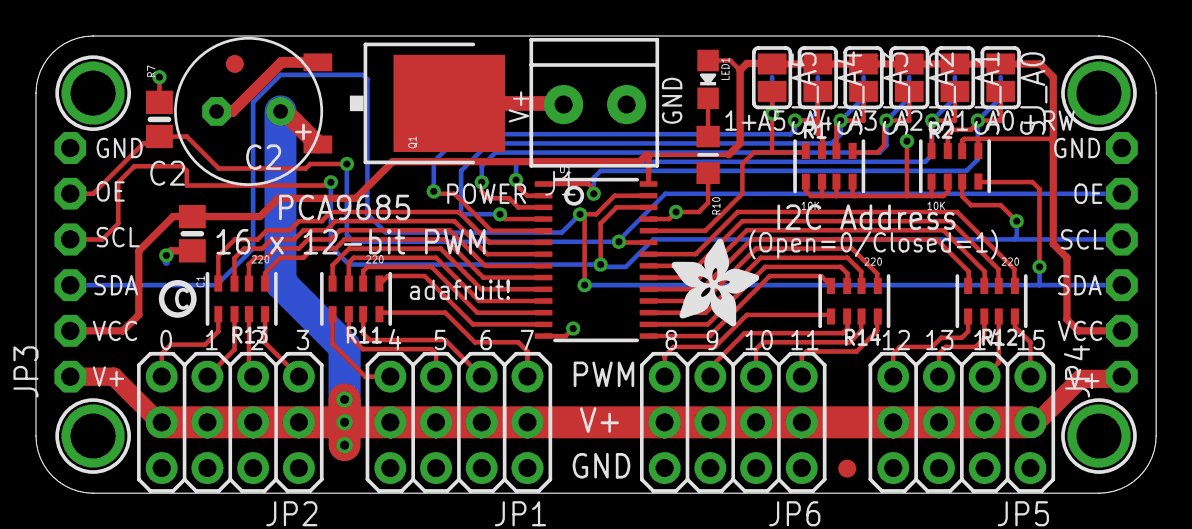
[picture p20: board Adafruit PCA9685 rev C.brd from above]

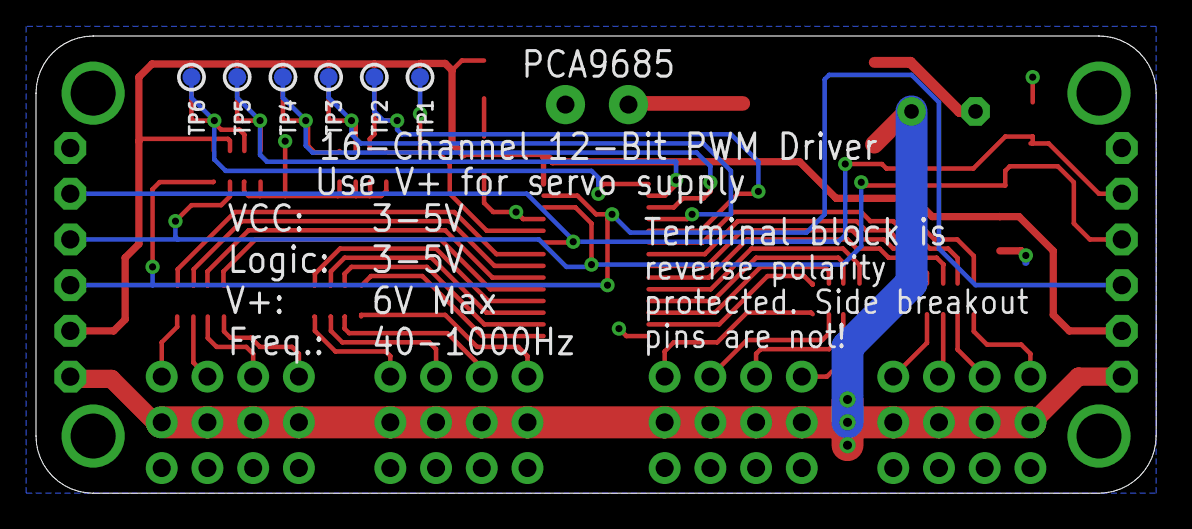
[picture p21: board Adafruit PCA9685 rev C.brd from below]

Board: 2 copper layers, 62.2 x 25.4 mm, 40 parts (6 on the bottom side), 46 nets.

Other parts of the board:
U$51: ADAFRUIT_5MM
U$54: PCBFEAT-REV-040

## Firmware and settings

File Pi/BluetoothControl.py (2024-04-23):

from gpiozero import Servo
from enum import Enum
import pygame
import threading
# from gpiozero.pins.pigpio import PiGPIOFactory
from time import sleep

# initialize pygame for services like joystick detection
pygame.init()

# initialize controller under pygame
Controller = pygame.joystick.Joystick(0)
Controller.init()
print ("Detected joystick " + Controller.get_name())

# values to store joystick state
triggers = [-1.0,-1.0] #left joystick, right joystick [-1 default, 1 pressed]
joystick1 = [0,0] #x axis [-1 left, 1 right] y axis [-1 up, 1 down]
joystick2 = [0,0] #x axis [-1 left, 1 right] y axis [-1 up, 1 down]
dpad = [0,0] #x axis [-1 left, 1 right] y axis [-1 down, 1 up]
buttons = [0, 0, 0, 0, 0, 0, 0, 0, 0, 0, 0, 0, 0, 0, 0] # a b x y lb rb share option lhat rhat

maxSteer = 80 # max angle (percent)
maxThrottle = 20 # max throttle (percent)

# values to write to servos
angle = 0 
throttle = 0

# initialize servo objects on gpio 11, 12
SteeringServo = Servo(17, initial_value = 0, min_pulse_width=1/1000, max_pulse_width=2/1000) 
DrivingServo = Servo(19, initial_value = 0,  min_pulse_width=1/1000, max_pulse_width=2/1000)

print("Waiting for ESC")
sleep(5)
print("Finished waiting")

# function to round num to range, returns 2 decimal point value
def num_to_range(num, inMin, inMax, outMin, outMax):
  return round(outMin + (float(num - inMin) / float(inMax - inMin) * (outMax- outMin)), 3)

# enum mappings for xbox controller readability
# triggers and joysticks are registered under the axis event, use enum for clarity
class XB_AXIS_MAP(int, Enum):
     LTRIGGER=4
     RTRIGGER=5
     LJOYX=0
     LJOYY=1
     RJOYX=2
     RJOYY=3

# main program loop
def bluetoothControl():
    SteeringServo.value = angle
    DrivingServo.value = throttle
    for event in pygame.event.get():
        if event.type == pygame.JOYAXISMOTION:
            if event.axis == XB_AXIS_MAP.LTRIGGER:
                triggers[0]=event.value + 1
            if event.axis == XB_AXIS_MAP.RTRIGGER:
                triggers[1]=event.value + 1
            if event.axis == XB_AXIS_MAP.LJOYX:
                joystick1[0]=event.value
            if event.axis == XB_AXIS_MAP.LJOYY:
                joystick1[1]=event.value
            if event.axis == XB_AXIS_MAP.RJOYX:
                joystick2[0]=event.value
            if event.axis == XB_AXIS_MAP.RJOYY:
                joystick2[1]=event.value
        if event.type == pygame.JOYHATMOTION: #d-pad
            dpad=[event.value[0],event.value[1]]
        if event.type == pygame.JOYBUTTONUP:
            buttons[event.button]=0
        if event.type == pygame.JOYBUTTONDOWN:
            buttons[event.button]=1
            
        #on pi, triggers[0] and [1] is flipped, windows order, triggers[1]-triggers[0]

        angle = round(joystick1[0], 3)
        throttle = num_to_range(triggers[0], 0, 2, 0, 0.3) - num_to_range(triggers[1], 0, 2, 0, 0.3)
    return str(angle, throttle)

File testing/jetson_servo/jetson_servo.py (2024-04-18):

#!/usr/bin/env python

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
import RPi.GPIO as GPIO
import time

output_pins = {
    'JETSON_XAVIER': 18,
    'JETSON_NANO': 33,
    'JETSON_NX': 33,
    'CLARA_AGX_XAVIER': 18,
    'JETSON_TX2_NX': 32,
    'JETSON_ORIN': 18,
    'JETSON_ORIN_NX': 33,
    'JETSON_ORIN_NANO': 33
}
output_pin = output_pins.get(GPIO.model, None)
if output_pin is None:
    raise Exception('PWM not supported on this board')


def main():
    # Pin Setup:
    # Board pin-numbering scheme
    GPIO.setmode(GPIO.BOARD)
    # set pin as an output pin with optional initial state of HIGH
    GPIO.setup(output_pin, GPIO.OUT, initial=GPIO.HIGH)
    print(output_pin)
    p = GPIO.PWM(output_pin, 100)
    val = 5
    incr = 5
    p.start(val)

    print("PWM running. Press CTRL+C to exit.")
    try:
        while True:
            time.sleep(0.25)
            if val >= 100:
                incr = -incr
            if val <= 0:
                incr = -incr
            val += incr
            p.ChangeDutyCycle(val)
    finally:
        p.stop()
        GPIO.cleanup()

if __name__ == '__main__':
    main()

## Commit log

2024-04-13 Jetson updates
2024-04-18 PWM tests
2024-05-06 Updated PCB to V3
    [Adafruit PCA9685 rev C.brd, Adafruit PCA9685 rev C.kicad_pcb, Adafruit PCA9685 rev C.kicad_sch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]
2024-05-13 completed board with labels included
    [pcb-v3.kicad_pcb, pcb-v3.kicad_sch]
2024-05-23 updated PCB
    [pcb-v3-B_Cu.gbr, pcb-v3-B_Mask.gbr, pcb-v3-B_Paste.gbr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]
2024-05-24 added mounting holes to PCB
    [pcb-v3-B_Cu.gbr, pcb-v3-B_Mask.gbr, pcb-v3-B_Paste.gbr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]
2024-05-28 Finishing touches
    [pcb-v3.kicad_pcb]
2024-05-28 forgot the Gerb files lol
    [pcb-v3-B_Cu.gbr, pcb-v3-B_Mask.gbr, pcb-v3-B_Paste.gbr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]
2024-10-16 Collect LIDAR data in CSV file
2024-11-09 Collect event camera events in DAT files

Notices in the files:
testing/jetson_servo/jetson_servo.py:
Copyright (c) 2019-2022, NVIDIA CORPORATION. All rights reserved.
